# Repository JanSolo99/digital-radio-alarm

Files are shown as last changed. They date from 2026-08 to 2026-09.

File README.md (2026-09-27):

# Digital Radio Alarm

A bedside internet radio alarm clock in a retro wood cabinet. An e-ink display shows the time,
date and a now-playing bar, lit from above by a dimmable warm light. Alarms pair a time with a
station and fade up from silence over about a minute. Everything you'd reach for half-asleep is a
physical knob or button - the phone stays in another room.

**Project site: https://jansolo99.github.io/digital-radio-alarm/**

Status: **design V1 final.** Next step is a full-size printed test model (see the print guide),
then parts and timber. Station management and alarm scheduling code are built and tested.

## Documentation

- [Build plan](https://jansolo99.github.io/digital-radio-alarm/build-plan.html) - the 14-step
  sequence from breadboard to burn-in, with acceptance criteria and review notes
- [Parts list](https://jansolo99.github.io/digital-radio-alarm/parts-list.html) - all 29 items
  with the gotchas worth knowing before ordering
- [Print guide](https://jansolo99.github.io/digital-radio-alarm/print-guide.html) - all 17
  printable parts as print-oriented STLs in `cad/stl/`, fasteners, and what to check on the test model
- [Enclosure concepts](https://jansolo99.github.io/digital-radio-alarm/enclosure-concepts.html) -
  the four directions considered, and which one won

## Specification

| | |
|---|---|
| Enclosure | Mitred hardwood, 180w × 120h × 100d mm, printed bezel and light hood |
| Brain | Raspberry Pi Zero 2 W |
| Display | 1.54" e-ink, 200×200 square, SPI, partial refresh |
| Audio | MAX98357A I2S amp into a Dayton Audio PC83-4 3" driver, sealed 0.64L chamber |
| Controls | EC11 rotary encoder with push-select + 3 tactile buttons |
| Light | 2700K 5V strip, PWM dimmed via MOSFET on GPIO12 or GPIO13 |
| Timekeeping | DS3231 battery-backed RTC on I2C |
| Power | 5V 3A USB, RCM-marked. SELV only - no mains inside the enclosure |

## Design decisions

- **No hosted backend.** Station discovery uses the free, open
  [Radio Browser](https://www.radio-browser.info) database; the stations you actually use live in
  `data/favorites.json` on the Pi. Nothing to host or keep running.
- **Alarms fire entirely on-device** - time and station are stored locally, so waking up never
  depends on a network round-trip.
- **Station search runs server-side, on the Pi.** Radio Browser's API only works through rotating
  mirror hosts discovered via DNS (`all.api.radio-browser.info`), and that DNS step isn't available
  to browser JavaScript. So `src/stations/radio_browser.py` handles lookup, retry and the required
  User-Agent, and `src/web/` serves its own page rather than calling the API from the browser.
- **A DS3231 RTC, despite the Pi not shipping with one.** A Pi restores a stale time at boot and
  only corrects once WiFi and NTP come up. Fine for most projects; not for an alarm clock.
- **The LED dimmer avoids GPIO18/19.** Those are the pins most PWM tutorials pick, and I2S claims
  both for the amplifier. Use GPIO12 or GPIO13.
- **Playback shells out to `mpv`** rather than using a Python audio library - handles the messy
  variety of internet radio stream formats for free.
- **The cabinet is sized around the speaker, not the electronics.** Small-speaker output is mostly
  cone area and enclosure volume. The first spec (50mm driver, ~1L box) had too little of both; a
  3" driver in its own sealed chamber is the single biggest thing separating "sounds like a small
  radio" from "sounds good". The 120mm height exists to give the driver frame real clearance.

## Structure

```
src/
  main.py          entry point, wires everything together
  alarm/           scheduling + storage        [built, tested]
  stations/        Radio Browser + favorites   [built, tested]
  web/             local management page       [built, partial]
  audio/           mpv wrapper, volume ramp    [not started]
  display/         e-ink driver + layout       [not started]
  input/           encoder + button handling   [not started]
  light/           PWM front-light control     [not started]
data/
  favorites.json   saved stations
  alarms.json      configured alarms
cad/               FreeCAD model (build_radio.py generates it), renders, STLs in cad/stl/
docs/              the GitHub Pages project site
systemd/
  digitalradioalarm.service       runs the clock app on boot
  digitalradioalarm-web.service   runs the management page on boot
```

`tests/` isn't created yet - it'll show up alongside the first module complex enough to need a
suite rather than the ad-hoc verification used so far.

## Setup

1. Flash Raspberry Pi OS Lite 64-bit with Raspberry Pi Imager, presetting hostname
   `radioclock.local`, WiFi, timezone and SSH.
2. `sudo apt install mpv libmpv-dev` and enable SPI + I2C via `raspi-config`.
3. `pip install -r requirements.txt`
4. Wire up per the [build plan](https://jansolo99.github.io/digital-radio-alarm/build-plan.html)
   step 3, and prove each subsystem on a breadboard before any woodwork.
5. Copy both `systemd/*.service` files to `/etc/systemd/system/`, then
   `sudo systemctl enable --now digitalradioalarm digitalradioalarm-web`.
6. Browse to `http://radioclock.local:8080/` from any device on the same WiFi to search stations
   and manage favorites.

The management page currently binds to all interfaces with no authentication. That's fine behind a
home router, but never port-forward it, and add a token before considering step 6 finished.

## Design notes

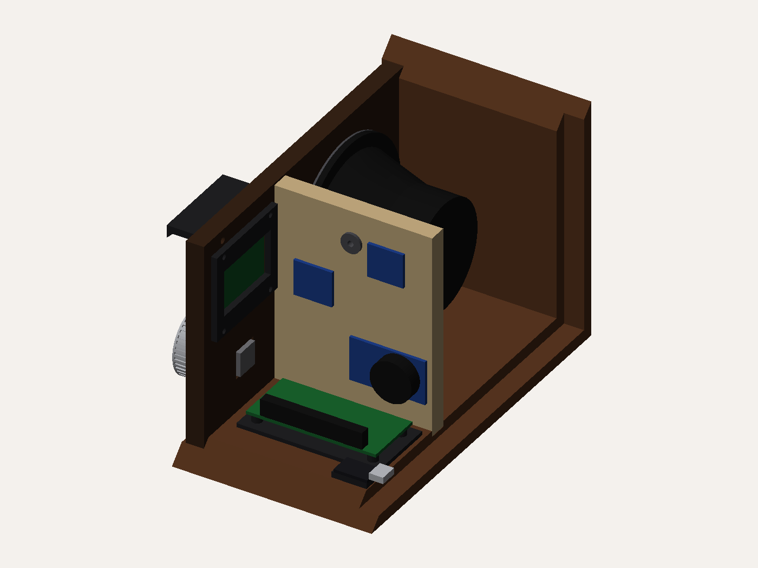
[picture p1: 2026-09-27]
docs/img/radio-electronics-bay.png

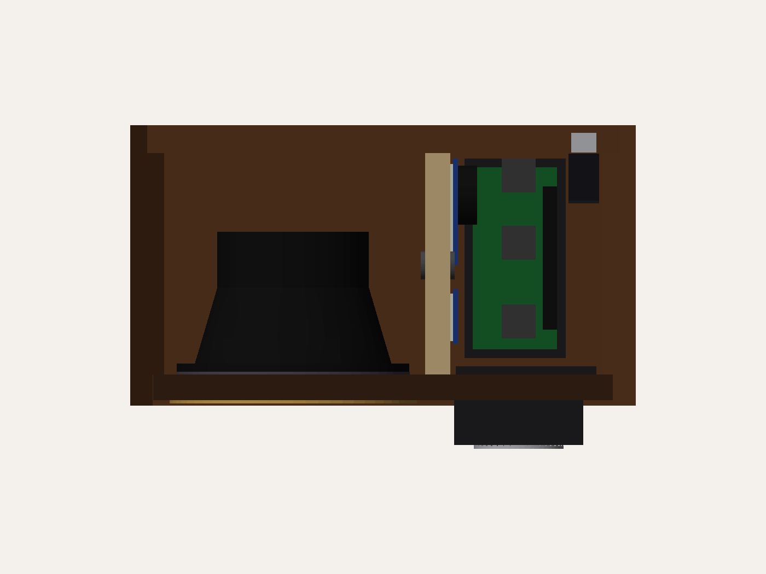
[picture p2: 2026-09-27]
docs/img/radio-plan-cutaway.png

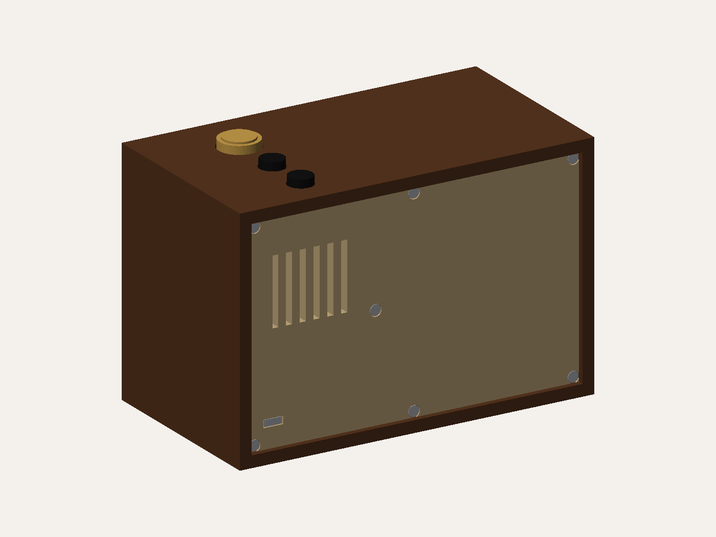
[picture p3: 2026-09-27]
docs/img/radio-rear-three-quarter.png

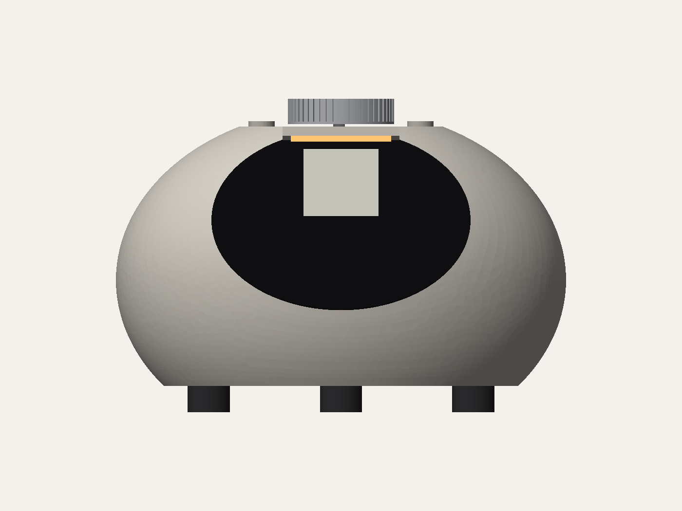
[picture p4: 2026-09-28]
docs/img/alt-pebble-front.png

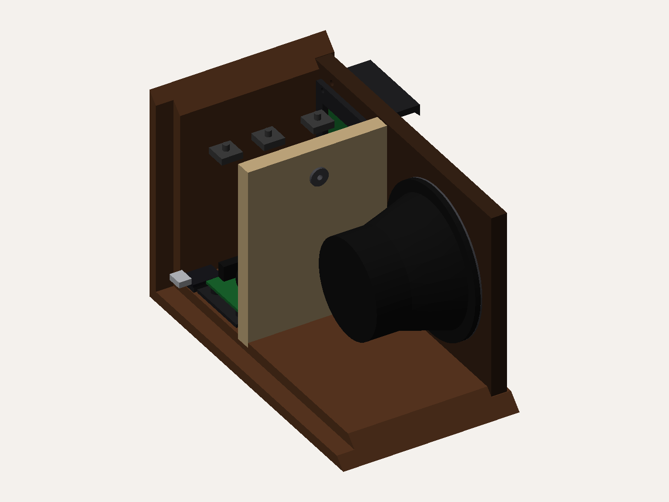
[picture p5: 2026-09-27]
docs/img/radio-speaker-chamber.png

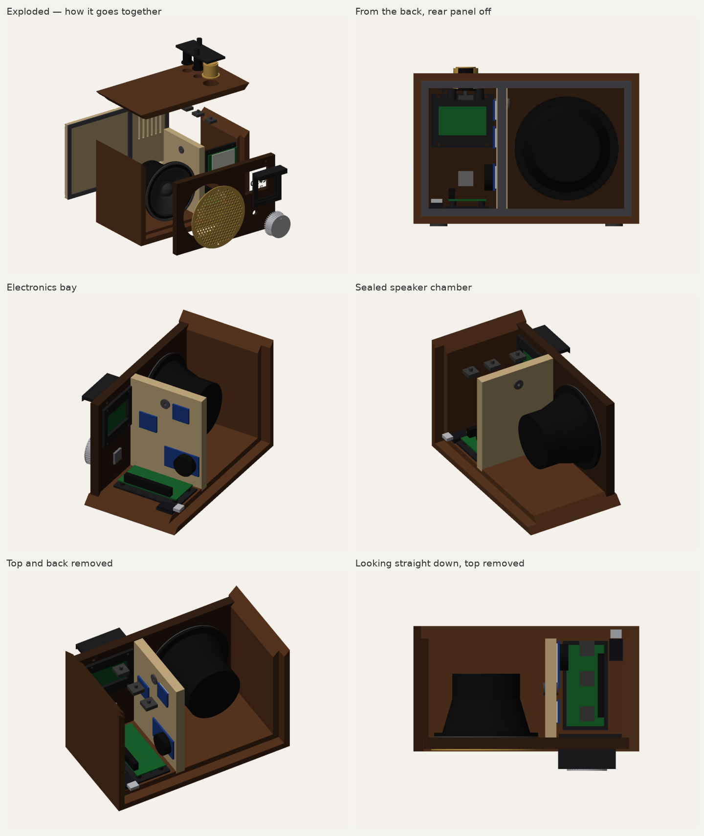
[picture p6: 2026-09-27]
docs/img/radio-inside-sheet.png

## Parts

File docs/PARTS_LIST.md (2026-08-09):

# Parts list

The parts list now lives on the project site, where it's kept alongside the build plan:

**https://jansolo99.github.io/digital-radio-alarm/parts-list.html**

Source: [`docs/parts-list.html`](parts-list.html).

This file used to hold a separate Markdown copy. It was replaced with this pointer rather than
maintained in parallel - two copies of a parts list drift, and the one you're not looking at is
always the stale one.

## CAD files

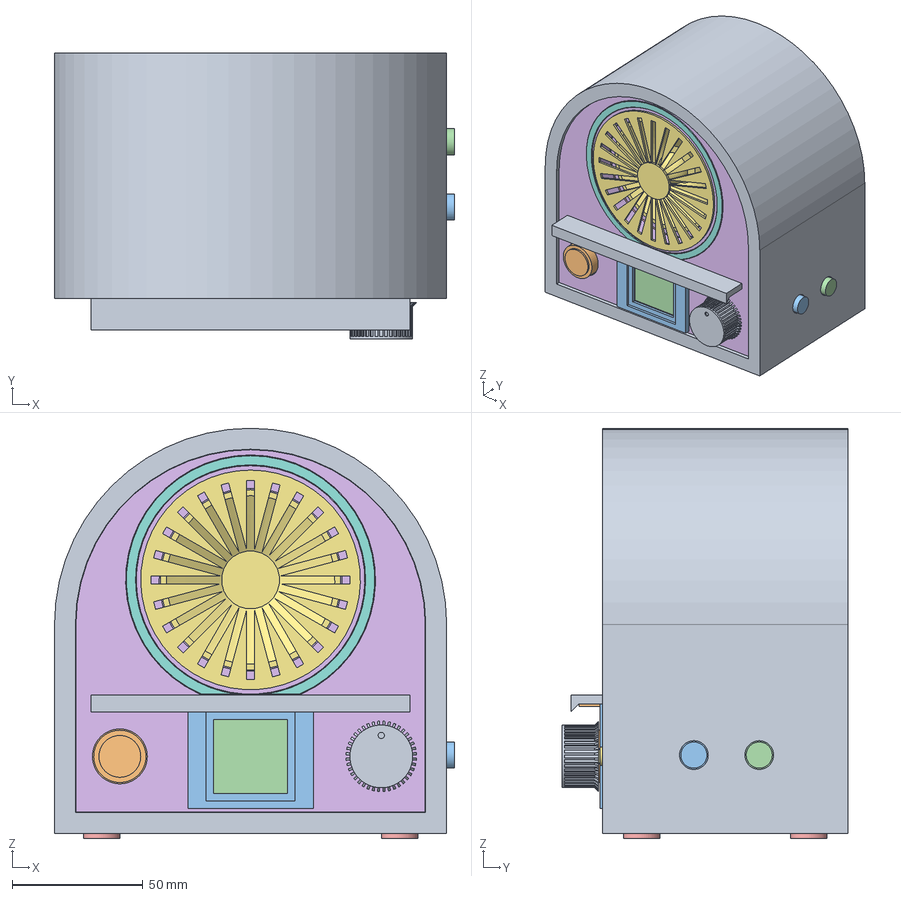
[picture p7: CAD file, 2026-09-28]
cad/alternatives/Sunrise.FCStd
153.0 x 109.5 x 157.0 mm
Carcass_Arch
Divider
Rear_Gasket
Rear_Panel
Felt_Feet
Front_Baffle
Sun_Grille
Halo_Diffuser
Horizon_Hood
LED_Strip_Display
Display_Bezel
EInk_Glass
EInk_Module_PCB
Display_Clamp
Encoder_EC11
Encoder_Nut
Switch_Snooze
Snooze_Bracket
Switch_Menu
Switch_Dismiss
Side_Button_Plate
Pi_Tray
Pi_Zero_2W
Pi_GPIO_Header
MAX98357A_Amp
DS3231_ZS042
RTC_Battery_Holder
MOSFET_Dimmer_2ch
Mount_Tape
USBC_Saddle
USBC_Breakout
USBC_Socket
Encoder_Knob
Button_Snooze
Button_Menu
Button_Dismiss
Driver_Gasket
Driver_PC83_4
Driver_Cone
Speaker_Wire_Grommet

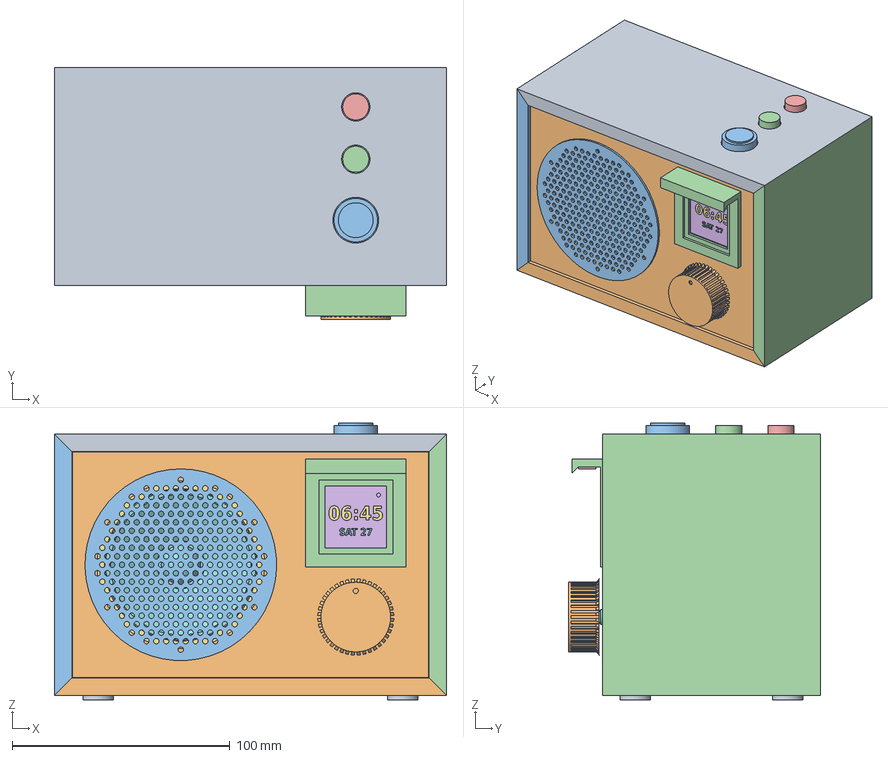
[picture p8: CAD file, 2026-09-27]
cad/DigitalRadioAlarm.FCStd
180.0 x 115.5 x 127.0 mm
Carcass_Top
Carcass_Bottom
Carcass_Left
Carcass_Right
Divider
Rear_Gasket
Rear_Panel
Rear_Screws
Felt_Feet
Front_Baffle
Speaker_Grille
Bezel_and_Hood
LED_Strip_COB
EInk_Glass
Face_Time
Face_Date
Face_AlarmArmed
Encoder_Knob
Button_Snooze
Button_Menu
Button_Dismiss
Driver_Gasket
Driver_PC83_4
Driver_Cone
Acoustic_Wadding
Speaker_Wire_Grommet
USBC_Saddle
USBC_Breakout
USBC_Socket
EInk_Module_PCB
Display_Clamp
Encoder_EC11
Encoder_Nut
Button_Plate
Switch_Snooze
Switch_Menu
Switch_Dismiss
Pi_Tray
Pi_Zero_2W
Pi_GPIO_Header
Mount_Tape
MAX98357A_Amp
DS3231_ZS042
RTC_Battery_Holder
MOSFET_Dimmer

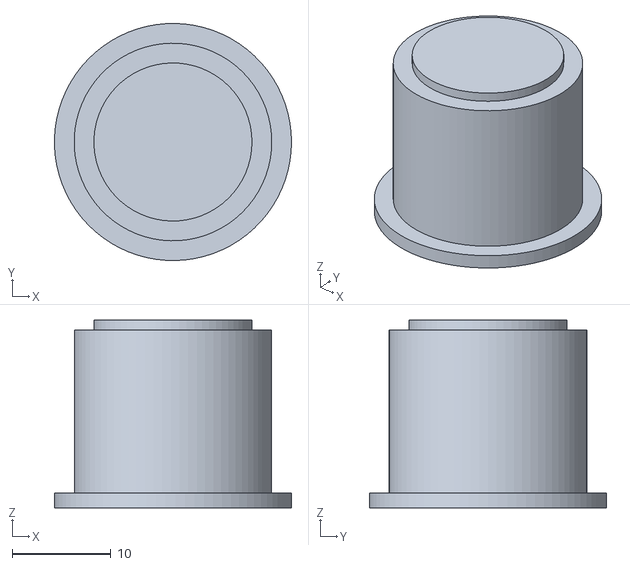
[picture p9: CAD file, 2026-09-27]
cad/stl/Button_Snooze.stl
24.0 x 24.0 x 19.0

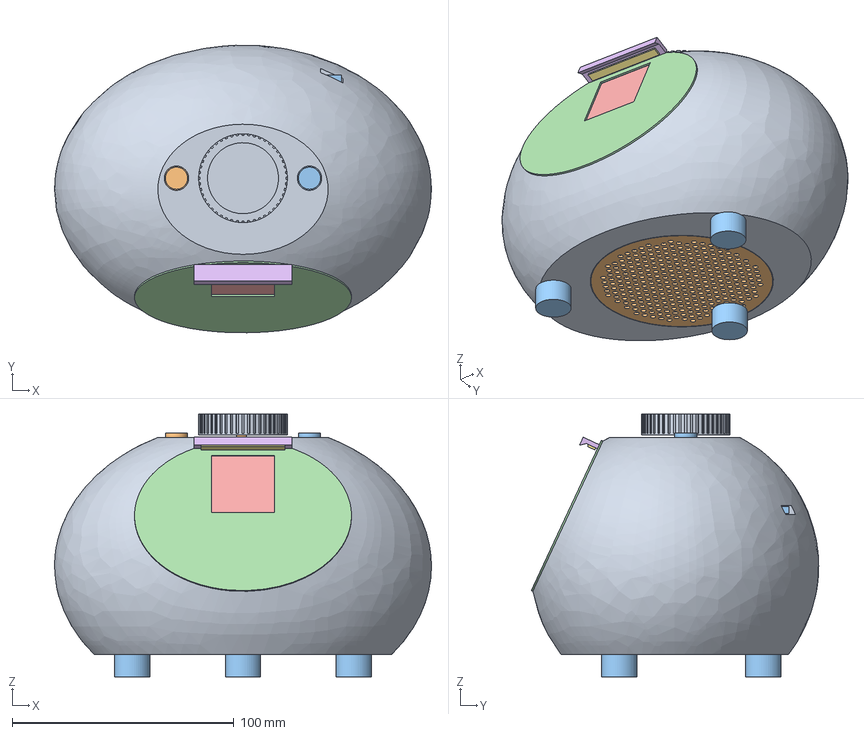
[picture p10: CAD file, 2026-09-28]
cad/alternatives/Pebble.FCStd
170.0 x 129.7 x 118.5 mm
Bottom_Grille
Feet
Glass_Face
EInk_Glass
Light_Eyebrow
LED_Strip
EInk_Module_PCB
Display_Clamp
Encoder_EC11
Encoder_Bracket
Encoder_Nut
Switch_Menu
Button_Plate_Menu
Switch_Dismiss
Button_Plate_Dismiss
Pi_Tray
Pi_Zero_2W
Pi_GPIO_Header
MAX98357A_Amp
MOSFET_Dimmer
DS3231_ZS042
RTC_Battery_Holder
Mount_Tape
USBC_Saddle
USBC_Breakout
USBC_Socket
Driver_Gasket
Driver_PC83_4
Driver_Cone
Shelf
Speaker_Wire_Grommet
Puck_Knob
Button_Menu
Button_Dismiss

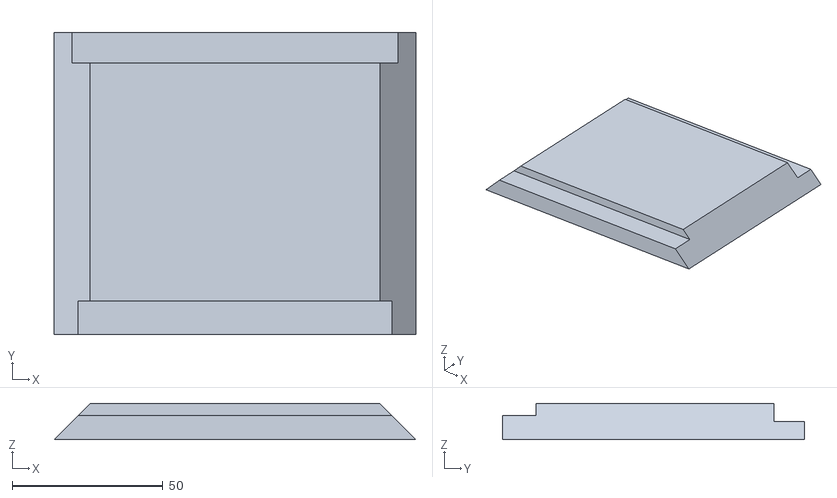
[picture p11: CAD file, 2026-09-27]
cad/stl/Carcass_Right.stl
120.0 x 100.0 x 12.0

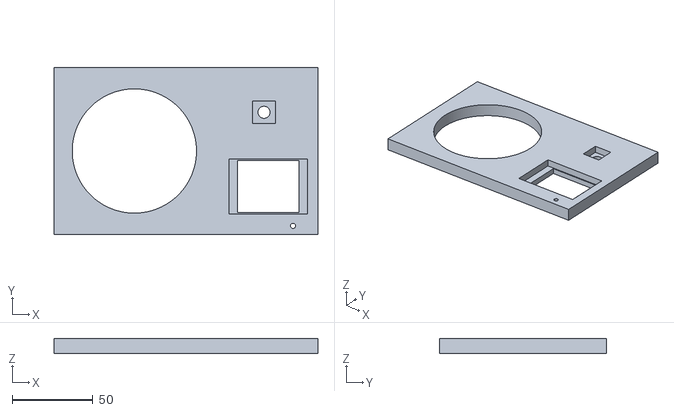
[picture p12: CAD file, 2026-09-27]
cad/stl/Front_Baffle.stl
163.6 x 103.6 x 9.00

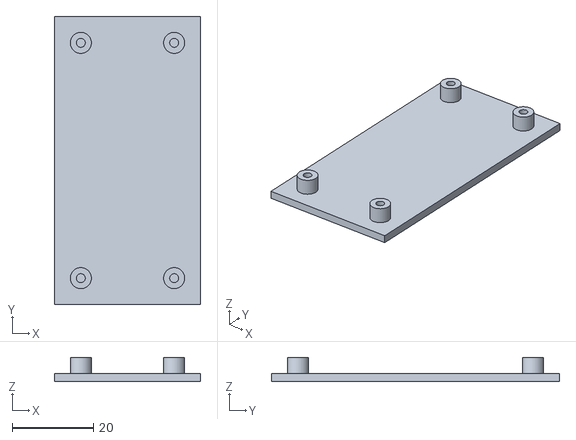
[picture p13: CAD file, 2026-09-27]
cad/stl/Pi_Tray.stl
36.0 x 71.0 x 6.00

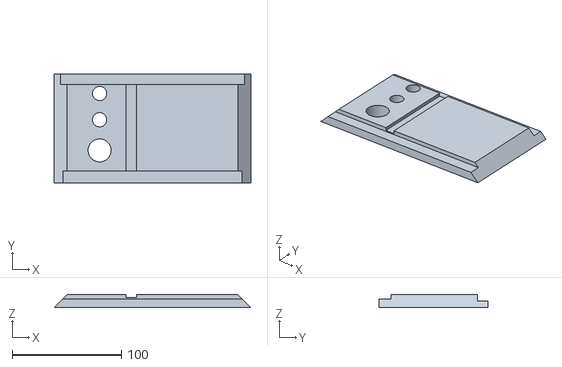
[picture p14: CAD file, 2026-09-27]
cad/stl/Carcass_Top.stl
180.0 x 100.0 x 12.0

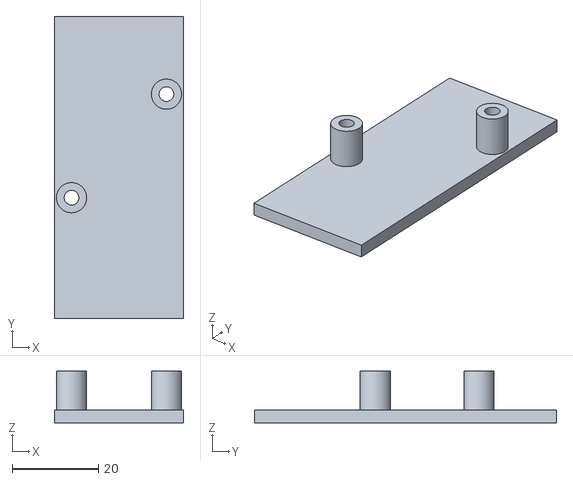
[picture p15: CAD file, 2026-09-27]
cad/stl/Button_Plate.stl
30.0 x 70.0 x 12.0

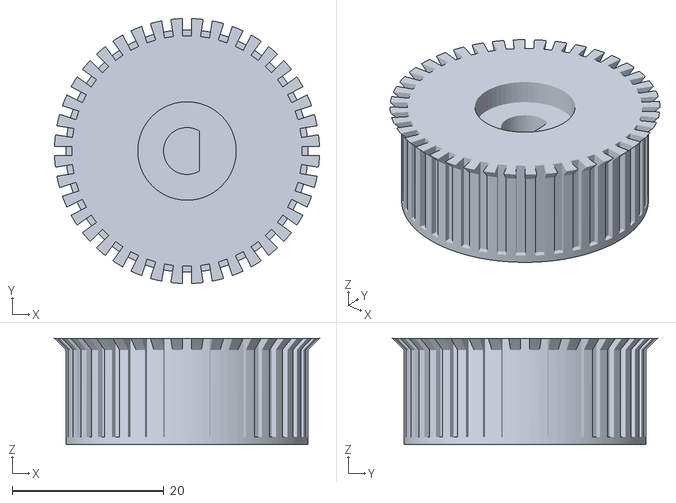
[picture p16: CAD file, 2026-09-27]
cad/stl/Encoder_Knob.stl
35.0 x 35.0 x 14.0

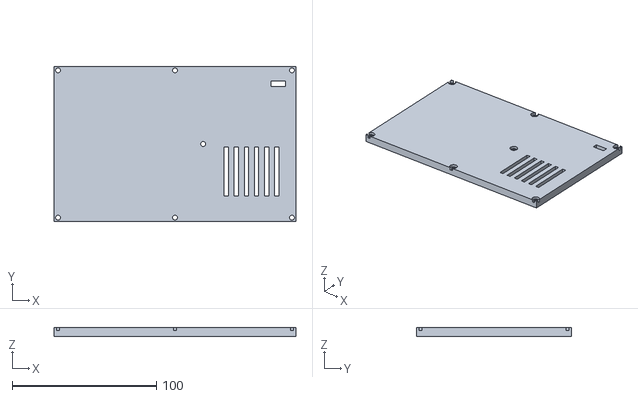
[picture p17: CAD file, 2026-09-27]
cad/stl/Rear_Panel.stl
167.6 x 107.6 x 6.00

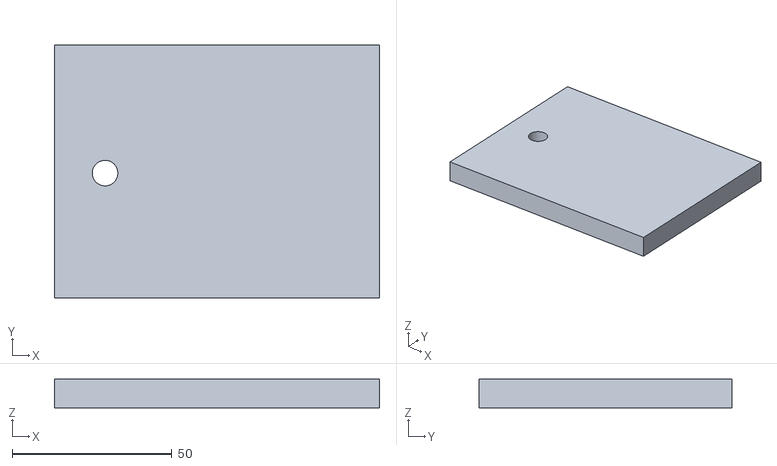
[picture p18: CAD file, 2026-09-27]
cad/stl/Divider.stl
101.6 x 79.0 x 9.00

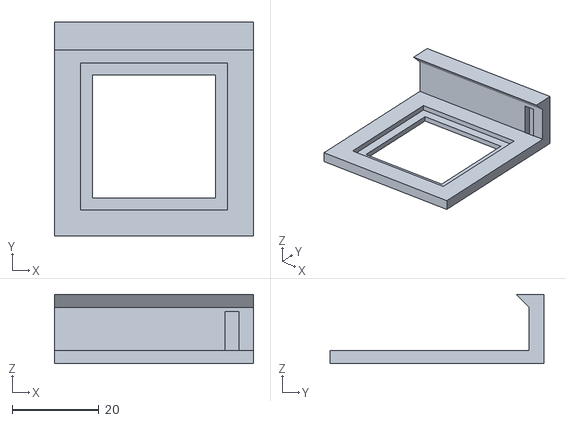
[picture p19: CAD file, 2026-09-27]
cad/stl/Bezel_and_Hood.stl
46.0 x 49.5 x 16.0

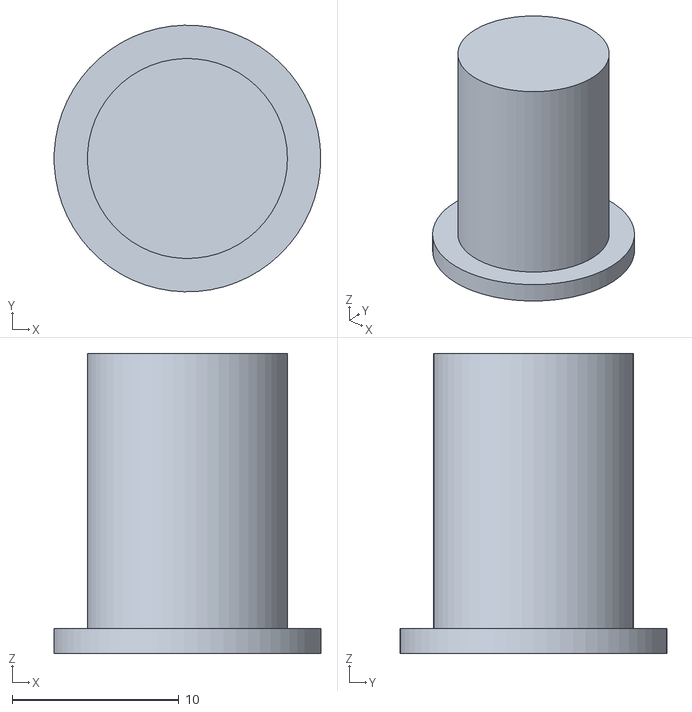
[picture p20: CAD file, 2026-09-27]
cad/stl/Button_Dismiss.stl
16.0 x 16.0 x 18.0

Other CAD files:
cad/stl/Carcass_Bottom.stl
cad/stl/Button_Menu.stl
cad/stl/Carcass_Left.stl
cad/stl/USBC_Saddle.stl
cad/stl/Display_Clamp.stl

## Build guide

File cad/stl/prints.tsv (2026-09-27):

part | role | x | y | z | bed | note
Carcass_Top | stand-in | 180.0 | 100.0 | 12.0 | flat | outer face down; mitres print as chamfers
Carcass_Bottom | stand-in | 180.0 | 100.0 | 12.0 | flat | outer face down
Carcass_Left | stand-in | 120.0 | 100.0 | 12.0 | flat | outer face down
Carcass_Right | stand-in | 120.0 | 100.0 | 12.0 | flat | outer face down
Front_Baffle | stand-in | 163.6 | 103.6 | 9.0 | flat | front face down; pocket and counterbore face up
Divider | stand-in | 101.6 | 79.0 | 9.0 | flat | flat
Rear_Panel | stand-in | 167.6 | 107.6 | 6.0 | flat | inner face down, so the screw counterbores face up
Speaker_Grille | stand-in | 88.0 | 88.0 | 1.2 | flat | flat; the real one is brass mesh
Bezel_and_Hood | final | 46.0 | 49.5 | 16.0 | flat | back face down; hood prints as a wall, lip is chamfered
Encoder_Knob | final | 35.0 | 35.0 | 14.0 | flat | front face down; bore and nut recess face up
Button_Snooze | final | 24.0 | 24.0 | 19.0 | flat | flange down
Button_Menu | final | 16.0 | 16.0 | 18.0 | flat | flange down
Button_Dismiss | final | 16.0 | 16.0 | 18.0 | flat | flange down
Button_Plate | final | 30.0 | 70.0 | 12.0 | flat | bosses up
Pi_Tray | final | 36.0 | 71.0 | 6.0 | flat | standoffs up
Display_Clamp | final | 50.0 | 43.0 | 3.0 | flat | flat
USBC_Saddle | final | 11.0 | 17.5 | 3.0 | flat | flat

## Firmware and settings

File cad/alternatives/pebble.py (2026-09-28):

"""Alternative design B - "Pebble".

A soft ellipsoidal body in the manner of a modern smart speaker:
  * the speaker fires DOWN into a 10mm gap under the body (as a HomePod
    mini does), so sound spreads evenly round the room and no grille
    breaks up the surface;
  * a front facet tilted 25 degrees back holds the e-ink display, angled
    up toward someone lying in bed, with a slim light "eyebrow" above it;
  * the top carries a rotating aluminium puck (the encoder: turn for
    volume or station, press to select, and press to snooze while the
    alarm rings) between two small buttons, menu and dismiss.

Inside, a horizontal shelf seals the lower half as the speaker chamber;
the electronics sit on top of the shelf. Printed as a 3mm shell (two
halves split at the shelf in practice), optionally fabric-wrapped.

Axes: X width, Y depth (front toward -Y), Z height. Origin on the table
under the centre. mm. Run inside FreeCAD; saves cad/alternatives/Pebble.FCStd.
"""

import importlib
import math
import os
import sys

import FreeCAD as App
import Part
from FreeCAD import Vector as V

sys.path.insert(0, os.path.dirname(os.path.abspath(__file__)))
import common as c  # noqa: E402

importlib.reload(c)
from common import box, fuse_all, placed, zcyl  # noqa: E402

A, B, C = 85.0, 65.0, 65.0             # ellipsoid semi-axes (x, y, z)
ZC = 50.0                              # ellipsoid centre height
Z_BASE, Z_TOP = 10.0, 108.0            # flat base and flat top
SHELL = 3.0
THETA = 25.0                           # display facet tilt back from vertical
FACET_POINT = V(0, -40.0, 90.0)       # cut deep enough that the facet reaches the top
SHELF_Z0, SHELF_Z1 = 66.0, 69.0
DRIVER_XY = (0.0, 5.0)
PUCK_XY = (0.0, 5.0)
PUCK_R = 20.0
TOP_BUTTONS = [("Menu", -30.0, 5.0), ("Dismiss", 30.0, 5.0)]
FEET = [(0.0, 40.0), (-50.0, -25.0), (50.0, -25.0)]

CHALK = (0.86, 0.84, 0.80)
CHALK_DARK = (0.78, 0.76, 0.72)
CHARCOAL = (0.20, 0.20, 0.21)

DOC_NAME = "Pebble"

N = V(0, -math.cos(math.radians(THETA)), math.sin(math.radians(THETA)))   # facet outward normal
UP = V(0, math.sin(math.radians(THETA)), math.cos(math.radians(THETA)))   # "up" within the facet


def ellipsoid(a, b, c_, zc):
    m = App.Matrix()
    m.scale(a, b, c_)
    s = Part.makeSphere(1.0).transformGeometry(m)
    s.translate(V(0, 0, zc))
    return s


def halfspace(point, normal, size=500.0):
    """Solid occupying everything on the `normal` side of the plane through `point`."""
    h = Part.makeBox(size, size, size, V(-size / 2, -size / 2, 0))
    rot = App.Rotation(V(0, 0, 1), normal)
    h.rotate(V(0, 0, 0), rot.Axis, math.degrees(rot.Angle))
    h.translate(point)
    return h


def body_solid(offset):
    """Outer body (offset=0) or the inner cavity (offset=SHELL)."""
    s = ellipsoid(A - offset, B - offset, C - offset, ZC)
    s = s.common(box(-200, -200, Z_BASE + offset, 200, 200, Z_TOP - offset))
    return s.cut(halfspace(FACET_POINT - N * offset, N))


def main():
    bld = c.Builder(DOC_NAME)
    add = bld.add

    outer = body_solid(0.0)
    inner = body_solid(SHELL)
    shell = outer.cut(inner)

    # Display facet: find the flat face, centre the display a little below its middle
    facet = max((f for f in outer.Faces if f.normalAt(0, 0).getAngle(N) < 0.05), key=lambda f: f.Area)
    # The display has to clear the shelf below and leave room for the light above,
    # so place it by height on the facet plane rather than at the facet's centroid.
    dcen = FACET_POINT + UP * ((86.7 - FACET_POINT.z) / UP.z)
    dpl = App.Placement(dcen, App.Rotation(V(1, 0, 0), -THETA))
    disp = c.display_local(SHELL, recess=1.0)
    shell = shell.cut(placed(disp["cut"], dpl))

    # Openings: driver (bottom), puck shaft and buttons (top), USB-C (back)
    dx, dy = DRIVER_XY
    shell = shell.cut(zcyl(c.DRIVER_CUTOUT_R, Z_BASE - 1, Z_BASE + SHELL + 1, dx, dy))
    shell = shell.cut(zcyl(41.3, Z_BASE - 1, Z_BASE + 1.2, dx, dy))                  # grille counterbore
    px, py = PUCK_XY
    shell = shell.cut(zcyl(4.5, Z_TOP - SHELL - 1, Z_TOP + 1, px, py))
    for _, bx, by in TOP_BUTTONS:
        shell = shell.cut(zcyl(5.5, Z_TOP - SHELL - 1, Z_TOP + 1, bx, by))
    shelf_top = SHELF_Z1
    usb_x, usb_z0 = 40.0, shelf_top + 3.0
    sock_z0 = usb_z0 + 1.6
    shell = shell.cut(box(usb_x - 5.0, 40, sock_z0 - 0.3, usb_x + 5.0, 70, sock_z0 + 3.6))
    add("Shell", shell, CHALK, "Body")

    # ── Display on the facet ────────────────────────────────────────────
    # The whole facet becomes a black glass face (like a smart display's front),
    # so the flat oval reads as the device's face rather than a cut-off patch.
    face_plate = facet.extrude(N * 0.8).cut(placed(disp["window"], dpl))
    add("Glass_Face", face_plate, (0.07, 0.07, 0.08), "Front")
    add("EInk_Glass", placed(disp["glass"], dpl), c.EPAPER, "Front")
    add("EInk_Module_PCB", placed(disp["module"], dpl), c.PCB_GREEN, "Electronics")
    brow = box(-22, -8.8, 17.5, 22, -0.8, 19.5)
    brow = brow.fuse(Part.Face(Part.makePolygon([V(-22, -8.8, 17.5), V(-22, -6.3, 17.5), V(-22, -8.8, 15.5),
                                                 V(-22, -8.8, 17.5)])).extrude(V(44, 0, 0))).removeSplitter()
    add("Light_Eyebrow", placed(brow, dpl), CHALK_DARK, "Front")
    add("LED_Strip", placed(box(-19, -5.3, 16.5, 19, -1.6, 17.5), dpl), c.WARM_LED, "Front", emissive=c.WARM_LED)
    mx0, mx1, mz0, mz1, my1 = disp["module_bounds"]
    # The inside narrows sharply toward the top front and the shelf is just below,
    # so the module is held by a strap across its middle, screwed to posts at the
    # widest point of the facet.
    clamp = box(mx0 - 6.5, my1, -4, mx1 + 6.5, my1 + 3, 4)
    bosses = [Part.makeCylinder(3.0, my1 - SHELL - 0.3, V(x_, SHELL + 0.3, 0), V(0, 1, 0))
              for x_ in (mx0 - 3.5, mx1 + 3.5)]
    add("Display_Clamp", placed(fuse_all([clamp] + bosses), dpl), c.PRINT_BLACK, "Electronics")

    # ── Down-firing driver, bottom grille, feet ─────────────────────────
    drv_pl = App.Placement(V(dx, dy, Z_BASE + SHELL), App.Rotation(V(1, 0, 0), 90))
    drv = c.driver_local()
    add("Driver_Gasket", placed(drv["gasket"], drv_pl), c.FOAM, "Speaker_Chamber")
    add("Driver_PC83_4", placed(drv["body"], drv_pl), c.MATTE_BLACK, "Speaker_Chamber")
    add("Driver_Cone", placed(drv["cone"], drv_pl), (0.20, 0.20, 0.21), "Speaker_Chamber")
    grille = zcyl(41.0, Z_BASE, Z_BASE + 1.2, dx, dy)
    holes = []
    for row in range(-10, 11):
        yy = row * 4.0 * 0.866
        for col in range(-10, 11):
            xx = col * 4.0 + (2.0 if row % 2 else 0.0)
            if math.hypot(xx, yy) < 36:
                holes.append(zcyl(1.2, Z_BASE - 1, Z_BASE + 2, dx + xx, dy + yy))
    add("Bottom_Grille", grille.cut(Part.makeCompound(holes)), CHARCOAL, "Body")
    add("Feet", fuse_all([zcyl(8.0, 0, Z_BASE, fx, fy) for fx, fy in FEET]), CHARCOAL, "Body")

    # ── Shelf: lid of the sealed chamber, floor of the electronics ──────
    shelf = inner.common(box(-200, -200, SHELF_Z0, 200, 200, SHELF_Z1))
    shelf = shelf.cut(zcyl(4.0, SHELF_Z0 - 1, SHELF_Z1 + 1, -45.0, 35.0))
    add("Shelf", shelf, c.PRINT_BLACK, "Speaker_Chamber")
    add("Speaker_Wire_Grommet", zcyl(5.0, SHELF_Z0 - 1.5, SHELF_Z0, -45.0, 35.0).fuse(
        zcyl(5.0, SHELF_Z1, SHELF_Z1 + 1.5, -45.0, 35.0)).fuse(zcyl(4.0, SHELF_Z0, SHELF_Z1, -45.0, 35.0)).cut(
        zcyl(1.5, SHELF_Z0 - 2, SHELF_Z1 + 2, -45.0, 35.0)), c.FOAM, "Speaker_Chamber")

    # ── Top: rotating puck on the encoder, two buttons ──────────────────
    top_in = Z_TOP - SHELL
    face = Z_TOP - 12.0                               # encoder mounting face, on a bracket under the top
    enc = box(px - 6, py - 6, face - 6.5, px + 6, py + 6, face)
    enc = enc.fuse(zcyl(3.5, face, face + c.ENC_BUSHING, px, py))
    enc = enc.fuse(zcyl(3.0, face + c.ENC_BUSHING, face + c.ENC_SHAFT, px, py).cut(
        box(px + 1.5, py - 4, face, px + 4, py + 4, face + 30)))
    add("Encoder_EC11", enc, (0.45, 0.45, 0.47), "Electronics")
    bracket = box(px - 12, py - 12, face, px + 12, py + 12, face + 3).cut(zcyl(3.6, face - 1, face + 4, px, py))
    bracket = fuse_all([bracket] + [zcyl(3.0, face + 3, top_in, px + sx, py) for sx in (-9.0, 9.0)])
    add("Encoder_Bracket", bracket, c.PRINT_BLACK, "Electronics")
    add("Encoder_Nut", zcyl(5.0, face + 3, face + 5, px, py).cut(zcyl(3.5, face, face + 6, px, py)), c.ALUMINIUM, "Electronics")

    shaft_tip = face + c.ENC_SHAFT
    puck_top = shaft_tip + 2.5
    puck = zcyl(PUCK_R, Z_TOP + 1.0, puck_top, px, py)
    grooves = []
    for i in range(48):
        g = box(-0.5, PUCK_R - 0.7, Z_TOP + 1.8, 0.5, PUCK_R + 1, puck_top + 1)
        g.rotate(V(0, 0, 0), V(0, 0, 1), 360.0 * i / 48)
        g.translate(V(px, py, 0))
        grooves.append(g)
    puck = puck.cut(Part.makeCompound(grooves))
    puck = puck.cut(zcyl(PUCK_R - 4, puck_top - 0.8, puck_top + 1, px, py))         # shallow dish
    puck = puck.cut(zcyl(3.1, Z_TOP, shaft_tip + 0.3, px, py).cut(box(px + 1.65, py - 4, 0, px + 4, py + 4, 200)))
    add("Puck_Knob", puck, c.ALUMINIUM, "Controls")

    for name, bx, by in TOP_BUTTONS:
        sw, cap, sw_z0 = c.tactile_button(5.0, Z_TOP + 2.0, top_in, bx, by)
        add(f"Switch_{name}", sw, (0.25, 0.25, 0.25), "Electronics")
        add(f"Button_{name}", cap, CHALK_DARK, "Controls")
        plate = box(bx - 8, by - 8, sw_z0 - 3, bx + 8, by + 8, sw_z0)
        plate = fuse_all([plate] + [zcyl(2.5, sw_z0, top_in, bx * 0.75, by + s) for s in (-9.0, 9.0)])
        add(f"Button_Plate_{name}", plate, c.PRINT_BLACK, "Electronics")

    # ── Electronics on the shelf ────────────────────────────────────────
    s1 = SHELF_Z1
    tray, board, header = c.pi_zero(-15.0, -12.0, s1)
    add("Pi_Tray", tray, c.PRINT_BLACK, "Electronics")
    add("Pi_Zero_2W", board, c.PCB_GREEN, "Electronics")
    add("Pi_GPIO_Header", header, c.MATTE_BLACK, "Electronics")
    t = s1 + 1.0
    add("MAX98357A_Amp", box(22, -2, t, 39.8, 17.4, t + 1.6), c.PCB_BLUE, "Electronics")
    add("MOSFET_Dimmer", box(22, 18, t, 40, 35, t + 1.6), c.PCB_BLUE, "Electronics")
    add("DS3231_ZS042", box(-50, -10, t, -28, 28, t + 1.6), c.PCB_BLUE, "Electronics")
    add("RTC_Battery_Holder", zcyl(10.5, t + 1.6, t + 8.6, -39.0, 12.0), c.MATTE_BLACK, "Electronics")
    add("Mount_Tape", fuse_all([box(22, -2, s1, 39.8, 17.4, t), box(22, 18, s1, 40, 35, t),
                                box(-50, -10, s1, -28, 28, t)]), (0.85, 0.85, 0.80), "Electronics")
    add("USBC_Saddle", box(usb_x - 5.5, 37, s1, usb_x + 5.5, 45, usb_z0), c.PRINT_BLACK, "Electronics")
    add("USBC_Breakout", box(usb_x - 5.5, 37.5, usb_z0, usb_x + 5.5, 46, sock_z0), c.PCB_BLACK, "Electronics")
    add("USBC_Socket", box(usb_x - 4.5, 44, sock_z0, usb_x + 4.5, 51.5, sock_z0 + 3.3), c.ALUMINIUM, "Electronics")

    bld.doc.recompute()

    chamber = inner.common(box(-200, -200, Z_BASE + SHELL, 200, 200, SHELF_Z0))
    for label in ("Driver_PC83_4", "Driver_Cone", "Driver_Gasket"):
        chamber = chamber.cut(bld.doc.getObjectsByLabel(label)[0].Shape)
    net_l = chamber.Volume / 1e6
    qtc, fc = c.sealed_box_alignment(net_l * c.WADDING_FACTOR)
    bb = outer.optimalBoundingBox()
    bld.doc.Comment = (f"Pebble · {bb.XLength:.0f}w x {Z_TOP:.0f}h x {bb.YLength:.0f}d mm · sealed chamber "
                       f"{net_l:.3f}L net · Qtc {qtc:.2f} · fc {fc:.0f}Hz · facet {facet.BoundBox.XLength:.0f}mm wide")
    App.Console.PrintMessage(bld.doc.Comment + "\n")
    bld.doc.saveAs(os.path.join(os.path.dirname(os.path.abspath(__file__)), "Pebble.FCStd"))
    return bld


if __name__ in ("__main__", "pebble"):
    main()

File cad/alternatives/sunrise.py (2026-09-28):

"""Alternative design A - "Sunrise".

An arched (tombstone) cabinet whose front is a night sky with a sun rising
over a horizon:
  * the speaker grille is the sun, with radial ray slots;
  * a translucent halo ring around it is a warm LED wake-up light that
    fades up before the radio does, and works as a night light;
  * a full-width "horizon" bar is also the hood that lights the display
    beneath it;
  * under the horizon: snooze (left), display (centre), knob (right).
    Menu and dismiss sit on the right side face, away from sleepy hands.

Same bought parts as V1. Inside, a horizontal divider makes the sealed
speaker chamber (the arch) and the electronics bay (the base).

Axes as V1: X width, Y depth (front face at Y=0), Z height. mm.
Run inside FreeCAD; saves cad/alternatives/Sunrise.FCStd.
"""

import math
import os
import sys

import FreeCAD as App
import Part
from FreeCAD import Vector as V

sys.path.insert(0, os.path.dirname(os.path.abspath(__file__)))
import importlib  # noqa: E402

import common as c  # noqa: E402

importlib.reload(c)                    # FreeCAD keeps modules cached between runs
from common import box, fuse_all, placed, xcyl, ycyl, zcyl  # noqa: E402

W, D = 150.0, 94.0
SPRING = 80.0                          # where the arch starts; radius is W/2
WALL = 12.0
FIT = 0.2
BAFFLE_Y0, BAFFLE_Y1 = 2.0, 11.0
FRONT_REBATE, REAR_REBATE = 4.0, 6.0
REAR_REBATE_Y = 84.0
GASKET_T, REAR_T = 1.5, 6.0
DIV_Z0, DIV_Z1 = 48.0, 54.0            # horizontal divider
DADO = 3.0

SUN_C = (W / 2, 97.0)                  # driver / sun centre (x, z)
HALO_R0, HALO_R1 = 44.0, 47.5
GRILLE_R = 42.0
DISPLAY_C = (W / 2, 29.5)
KNOB_C = (125.0, 29.5)
SNOOZE_C = (25.0, 29.5)
SIDE_BUTTONS = [("Menu", 35.0, 30.0), ("Dismiss", 60.0, 30.0)]   # (name, y, z) on the right face

OAK = (0.74, 0.58, 0.40)
NIGHT = (0.10, 0.13, 0.22)
NIGHT_BLACK = (0.06, 0.07, 0.11)
BIRCH_PLY = (0.80, 0.70, 0.52)
HALO = (1.0, 0.72, 0.38)

DOC_NAME = "Sunrise"


def arch_prism(x0, x1, z0, y0, y1):
    """Tombstone profile (flat bottom, semicircular top) extruded along Y."""
    r = (x1 - x0) / 2
    cx = (x0 + x1) / 2
    a = V(x0, y0, z0)
    b = V(x1, y0, z0)
    c1 = V(x1, y0, SPRING)
    top = V(cx, y0, SPRING + r)
    d = V(x0, y0, SPRING)
    wire = Part.Wire([Part.LineSegment(a, b).toShape(), Part.LineSegment(b, c1).toShape(),
                      Part.Arc(c1, top, d).toShape(), Part.LineSegment(d, a).toShape()])
    return Part.Face(wire).extrude(V(0, y1 - y0, 0))


def main():
    bld = c.Builder(DOC_NAME)
    add = bld.add
    fr, rr = FRONT_REBATE, REAR_REBATE

    # ── Arch carcass: a 12mm tube of the tombstone profile ──────────────
    outer = arch_prism(0, W, 0, 0, D)
    inner = arch_prism(WALL, W - WALL, WALL, -1, D + 1)
    carcass = outer.cut(inner)
    carcass = carcass.cut(arch_prism(WALL - fr, W - WALL + fr, WALL - fr, -1, BAFFLE_Y1))
    carcass = carcass.cut(arch_prism(WALL - rr, W - WALL + rr, WALL - rr, REAR_REBATE_Y, D + 1))
    carcass = carcass.cut(box(WALL - DADO, -1, DIV_Z0 - FIT, W - WALL + DADO, D + 1, DIV_Z1 + FIT))
    for _, by, bz in SIDE_BUTTONS:
        carcass = carcass.cut(xcyl(5.5, W - WALL - 1, W + 1, by, bz))
    add("Carcass_Arch", carcass, OAK, "Cabinet")
    add("Divider", box(WALL - DADO + FIT, BAFFLE_Y1, DIV_Z0, W - WALL + DADO - FIT, REAR_REBATE_Y, DIV_Z1).cut(
        zcyl(4.0, DIV_Z0 - 1, DIV_Z1 + 1, 60.0, 60.0)), BIRCH_PLY, "Cabinet")

    # ── Baffle: the night sky ───────────────────────────────────────────
    baffle = arch_prism(WALL - fr + FIT, W - WALL + fr - FIT, WALL - fr + FIT, BAFFLE_Y0, BAFFLE_Y1)
    sx, sz = SUN_C
    baffle = baffle.cut(ycyl(c.DRIVER_CUTOUT_R, 0, BAFFLE_Y1 + 1, sx, sz))
    halo_groove = ycyl(HALO_R1 + 0.3, BAFFLE_Y0 - 1, BAFFLE_Y0 + 5, sx, sz).cut(
        ycyl(HALO_R0 - 0.3, BAFFLE_Y0 - 2, BAFFLE_Y0 + 6, sx, sz))
    baffle = baffle.cut(halo_groove)
    wire_z = sz - (HALO_R0 + HALO_R1) / 2
    baffle = baffle.cut(ycyl(1.5, BAFFLE_Y0 + 4, BAFFLE_Y1 + 1, sx, wire_z))            # halo LED wires...
    baffle = baffle.cut(box(sx - 1.5, BAFFLE_Y1 - 2, DIV_Z0 - 4, sx + 1.5, BAFFLE_Y1 + 1, wire_z))   # ...down to the bay

    disp = c.display_local(BAFFLE_Y1 - BAFFLE_Y0)
    dpl = App.Placement(V(DISPLAY_C[0], BAFFLE_Y0, DISPLAY_C[1]), App.Rotation())
    baffle = baffle.cut(placed(disp["cut"], dpl))
    enc = c.encoder_local(BAFFLE_Y1 - BAFFLE_Y0)
    kpl = App.Placement(V(KNOB_C[0], BAFFLE_Y0, KNOB_C[1]), App.Rotation())
    baffle = baffle.cut(placed(enc["cut"], kpl))
    snx, snz = SNOOZE_C
    baffle = baffle.cut(ycyl(10.5, BAFFLE_Y0 - 1, BAFFLE_Y1 + 1, snx, snz))
    baffle = baffle.cut(ycyl(12.5, BAFFLE_Y0 + 3.5, BAFFLE_Y1 + 1, snx, snz))          # flange counterbore
    add("Front_Baffle", baffle, NIGHT, "Front")

    # ── The sun: ray grille + halo light ────────────────────────────────
    sun = ycyl(GRILLE_R, BAFFLE_Y0 - 1.2, BAFFLE_Y0, sx, sz)
    rays = []
    for i in range(24):
        ray = box(-1.5, BAFFLE_Y0 - 2, 11, 1.5, BAFFLE_Y0 + 1, GRILLE_R - 4)
        ray.rotate(V(0, 0, 0), V(0, 1, 0), 360.0 * i / 24)
        ray.translate(V(sx, 0, sz))
        rays.append(ray)
    sun = sun.cut(Part.makeCompound(rays))
    add("Sun_Grille", sun, c.BRASS, "Front")
    # ── Horizon bar (also the display's light hood) ─────────────────────
    hz0 = DISPLAY_C[1] + 20.0
    # The sun sits just behind the horizon: its halo's lowest arc tucks in behind the bar.
    halo = ycyl(HALO_R1, BAFFLE_Y0 - 0.4, BAFFLE_Y0 + 2, sx, sz).cut(
        ycyl(HALO_R0, BAFFLE_Y0 - 1, BAFFLE_Y0 + 3, sx, sz))
    halo = halo.cut(box(0, -20, 0, W, BAFFLE_Y0 + 0.3, hz0 + 3.8))
    add("Halo_Diffuser", halo, HALO, "Front", emissive=HALO)
    horizon = box(WALL + 2, BAFFLE_Y0 - 14, hz0, W - WALL - 2, BAFFLE_Y0, hz0 + 3.5)
    lip = Part.Face(Part.makePolygon([V(WALL + 2, BAFFLE_Y0 - 14, hz0), V(WALL + 2, BAFFLE_Y0 - 11, hz0),
                                      V(WALL + 2, BAFFLE_Y0 - 14, hz0 - 3), V(WALL + 2, BAFFLE_Y0 - 14, hz0)])
                    ).extrude(V(W - 2 * WALL - 4, 0, 0))
    add("Horizon_Hood", horizon.fuse(lip).removeSplitter(), c.BRASS, "Front")
    add("LED_Strip_Display", box(DISPLAY_C[0] - 20, BAFFLE_Y0 - 11, hz0 - 1, DISPLAY_C[0] + 20, BAFFLE_Y0 - 3, hz0),
        c.WARM_LED, "Front", emissive=c.WARM_LED)
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

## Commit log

2026-08-09 Scaffold project: hardware plan, parts list, and station management
    Repo structure for the DIY e-ink internet radio alarm clock, plus a
    working src/web/ + src/stations/ module that searches Radio Browser
    and manages local favorites from a phone on the home network. Docs
    site under docs/ mirrors the plan, parts list, and enclosure concepts
    for GitHub Pages.
2026-08-09 Add build plan, alarm module, and reviewed parts list
    Incorporates the 14-step build sequence generated with blueprinthome.app,
    reviewed against the electronics and existing code. Four corrections
    flagged inline on the build plan and carried into the parts list:
    - LED PWM dimmer conflicts with I2S on GPIO18/19; move to GPIO12/13
    - No RTC was specified; DS3231 + CR2032 added, since a Pi restores a
    stale time at boot and only corrects once NTP is reachable
    - LED strip must be 5V, not 12V - there is no 12V rail in this build
    - Station management already solved via Radio Browser search, rather
    than pasting stream URLs by hand
    Also resolves the two open design questions (retro wood cabinet;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
2026-08-10 Resize cabinet around a 3-inch driver
    Sized the design against a Tivoli Model One (114x213x133mm, 3" ported
    driver). The original 145x95x70mm cabinet with a 50mm driver had too
    little cone area and too little enclosure volume to sound like anything
    but a small radio.
    Cabinet is now 180x120x100mm external, ~1.1L internal. Height was set
    by driver clearance: at 105mm tall with 12mm walls the internal height
    is 81mm against an ~80mm driver frame, which is not buildable.
    Parts follow: 3" 4ohm driver, 85-90mm grille, hole saw instead of a
    Forstner bit for the larger cutout, printed bass port, acoustic wadding,
    and wider stock for the carcass.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
2026-08-10 Switch to a 1.54in square e-ink display
    Square 200x200 panel instead of the 2.9in landscape. Fits the 180mm
    baffle with real margin beside the 90mm grille, balances better against
    a round grille, and costs less.
    Clock face becomes time over numbered date, plus an armed-alarm
    indicator - that indicator replaces checking your phone at bedtime,
    which is the point of the build. Drops the persistent now-playing bar;
    e-ink refreshes too slowly for a scrolling ticker to read well, and the
    same constraint favours one-station-at-a-time over a scrolling list.
    Bezel now specifies a recessed window that reads as a dial window
    rather than a screen.
    Flagged before ordering: the active area is only ~27.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
2026-08-10 Document wall thickness and control mounting depth
    10-12mm is the right zone for panels this small; 12mm stays specced.
    Adds the constraint that actually bites at assembly: EC11 bushings are
    commonly 5-7mm, so the thread won't emerge through a 12mm panel to take
    its nut. Counterbore from behind, or use the printed control plate.
2026-09-27 Add FreeCAD model of the radio
    cad/build_radio.py generates the full assembly in FreeCAD: mitred 12mm
    carcass, recessed baffle, brass grille, 3" driver, dial-window bezel
    with LED hood, 1.54" e-ink with a sample clock face, knurled encoder
    knob, three top-deck buttons, rear panel with bass port, and the Pi,
    amp and RTC on the floor. Checked for interference; two clashes found
    and fixed (e-ink glass vs baffle opening, Pi vs rear cleat).
    cad/render_views.py renders review images outside FreeCAD with a small
    z-buffer rasteriser, since FreeCAD's screenshot path returns blank or
    scrambled images on this Wayland setup.
    [DigitalRadioAlarm.FCStd]
2026-09-27 Interior pass: sealed speaker chamber, electronics bay, PC83-4 driver
    A 9mm ply divider, glued into dados in the top and bottom boards,
    splits the cabinet into a sealed speaker chamber and an electronics
    bay. The chamber contains only the driver, wadding and one sealed wire
    pass-through; buttons, display, encoder, cable and vents all moved to
    the bay side so nothing else pierces it.
    Bass port removed: at ~170Hz it was mistuned, and a port needs a
    leak-free box and a specific driver. Sealed is simpler and doesn't chuff.
    Driver chosen: Dayton Audio PC83-4. In the measured 0.64L chamber it
    gives Qtc ~1.0, fc ~154Hz; 4 ohm suits the MAX98357A. The Tang Band
    W3-2141 is the documented upgrade bu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
    [DigitalRadioAlarm.FCStd]
2026-09-27 Add inside views of the radio
    Renderer gains per-part offsets for exploded views. New images: exploded
    assembly, rear panel off, electronics bay, sealed speaker chamber, plus
    a combined inside sheet. The overview page shows them.
2026-09-27 Design V1: printable test model, verified dimensions, missed items fixed
    Printability
    - Every non-bought part exports as a print-oriented STL (cad/stl/),
    including full-size stand-ins for the timber parts, so a complete test
    model can be printed before cutting wood. 17 parts, ~410g, no supports.
    - Automated check on every STL: closed, manifold, and no overhang beyond
    45 degrees except two sub-4mm bridges. Fixed a 1mm flat step on the hood
    lip, groove-end ceilings on the knob, and flipped the rear panel so its
    screw counterbores face up.
    - Design rule: fits a 220x210 bed. The 180mm boards cannot fit a 180 bed.
    Dimensions checked against manufacturer data
    - e-ink glass is 37.32 x 31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
    [Bezel_and_Hood.stl, Button_Dismiss.stl, Button_Menu.stl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]
2026-09-27 Binary STLs, and target the Elegoo Centauri Carbon
    STLs were ASCII at a very fine tolerance (the grille alone was 60MB).
    Now binary at 0.02mm chordal tolerance: 3.5MB for all 17 parts, still
    closed and manifold, same overhang results.
    Target printer is the Canberra maker space's Elegoo Centauri Carbon
    (256mm cube, 0.4mm nozzle, PLA); every part fits flat. Print guide
    specifies PLA throughout.
    Claude-Session: https://claude.ai/code/session_01CFh6y5NXQoV6qgo3zeqiHa
    [Bezel_and_Hood.stl, Button_Dismiss.stl, Button_Menu.stl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]
2026-09-28 Add two alternative designs: Sunrise and Pebble
    Both modelled in FreeCAD around the same bought parts as V1 (PC83-4,
    1.54in e-ink, EC11, Pi Zero 2 W), sharing component models in
    cad/alternatives/common.py. Each is collision-free, geometrically valid,
    and has a sealed speaker chamber pierced only by the driver and a
    sealed wire grommet.
    Sunrise (150w x 155h x 94d, 0.63L, Qtc 1.04): arched cabinet, sunburst
    grille with a halo that doubles as a wake-up light, a horizon bar that
    is also the display hood, snooze and knob on the front, menu and
    dismiss on the side.
    Pebble (170w x 108h x 129d, 0.69L, Qtc 1.00): printed ellipsoid shell,
    down-firing speaker into a gap under the body, a black glass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
    [Pebble.FCStd, Sunrise.FCStd]
